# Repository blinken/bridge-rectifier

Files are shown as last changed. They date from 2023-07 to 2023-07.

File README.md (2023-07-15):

# Bench bridge rectifier

A really simple project - a bridge rectifier, with a fuse, designed to be
inserted into an aluminium case with banana plugs in and out. I wanted this to
safely dump 2A @ 250V AC into my DC electronic load (don't ask!)

The board is designed with 5mm separation between different nets.

The PCB is designed to slide in to rails in the aluminium extrusion, and the
edges of the PCB are left exposed so earth is electrically connected to the
enclosure.

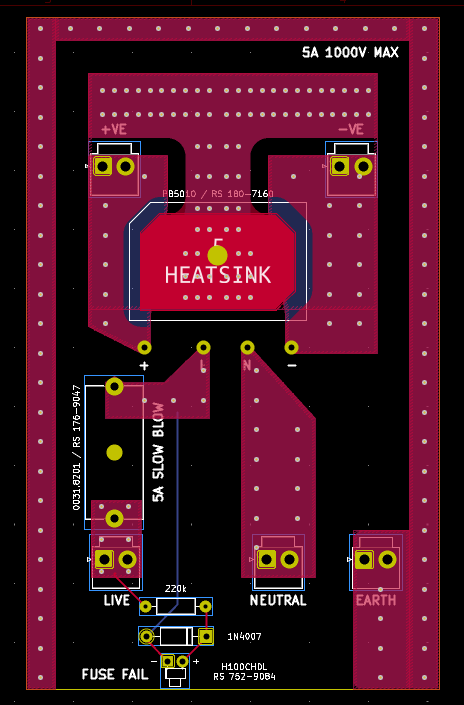
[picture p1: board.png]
Bridge rectifier PCB


## Bill of materials

 * Vishay PB5010 Bridge Rectifier, 45A, 1000V, 4-Pin (RS 180-7160)
 * 5x JST, VH, B2P, 2 Way, 1 Row, Straight PCB Header
 * Schurter 10A PCB Mount Fuse Holder 0031.8201 (RS 176-9047)
 * H100CHDL LED (RS 752-9084)
 * 1N4007 diode
 * 220k resistor, 0.25W or 0.5W
 * An aluminium extrusion case suitable for a 70x114mm board - eg, [AliExpress](https://www.aliexpress.com/item/1005003326971939.html)

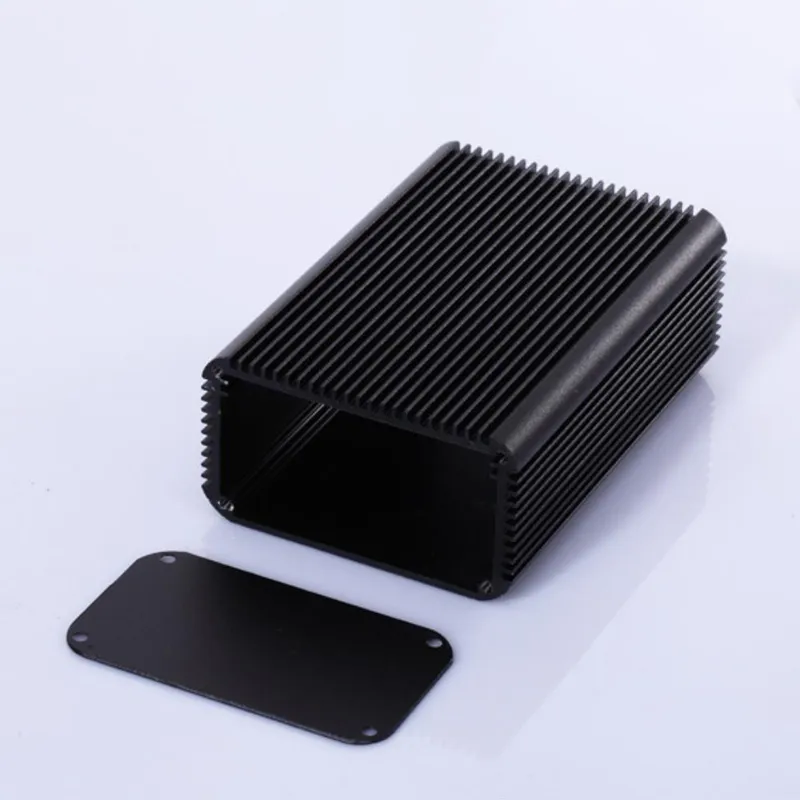
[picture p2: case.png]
Aluminium enclosure 70x115mm internal size

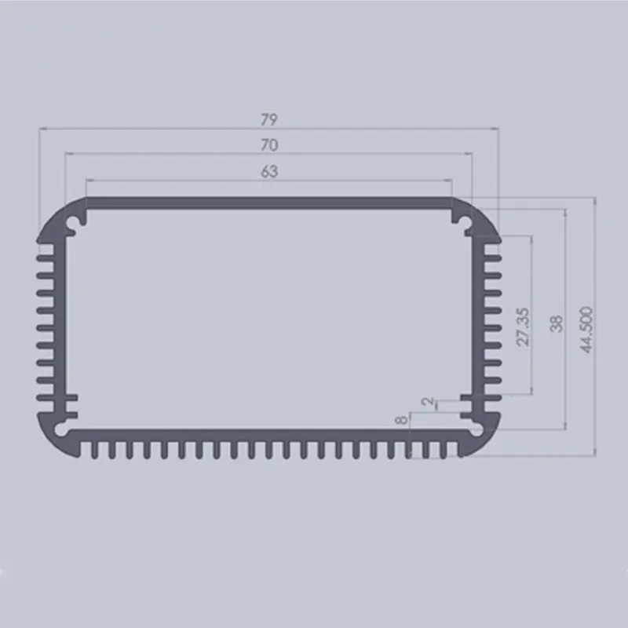
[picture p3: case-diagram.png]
Aluminium enclosure, diagram with dimensions


## License

[CC BY-SA 3.0](https://creativecommons.org/licenses/by-sa/3.0/)

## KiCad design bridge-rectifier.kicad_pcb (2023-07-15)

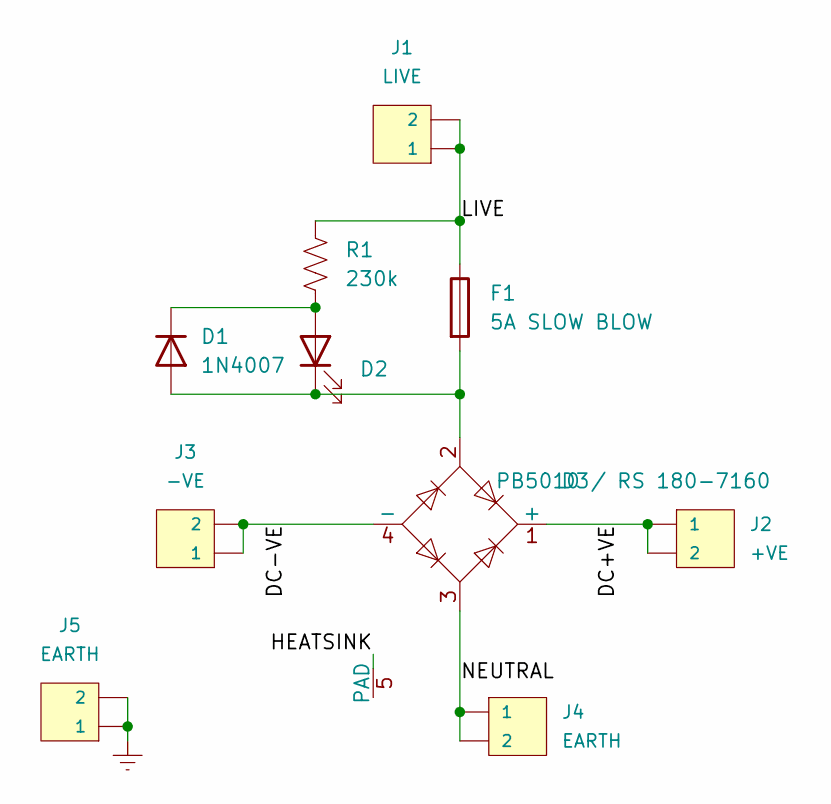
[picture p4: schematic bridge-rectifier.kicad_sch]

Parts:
D1: 1N4007; D_DO-41_SOD81_P10.16mm_Horizontal
D2: H100CHDLRS 752-9084; LED_D1.8mm_W1.8mm_H2.4mm_Horizontal_O1.27mm_Z1.6mm
D3: PB5010 / RS 180-7160; Vishay_Diode_Bridge_Rectifier_PB
F1: 5A SLOW BLOW; Fuseholder_Cylinder-5x20mm_Schurter_0031_8201_Horizontal_Op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
J1: LIVE; JST_VH_B2P-VH_1x02_P3.96mm_Vertical; LCSC C131337
J2: +VE; JST_VH_B2P-VH_1x02_P3.96mm_Vertical; LCSC C131337
J3: -VE; JST_VH_B2P-VH_1x02_P3.96mm_Vertical; LCSC C131337
J4, J5: EARTH; JST_VH_B2P-VH_1x02_P3.96mm_Vertical; LCSC C131337
R1: 230k; R_Axial_DIN0207_L6.3mm_D2.5mm_P10.16mm_Horizontal

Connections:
/DC+VE: D3.1 (+), J2.1, J2.2
/DC-VE: D3.4 (-), J3.1, J3.2
/HEATSINK: D3.5 (PAD)
/LIVE: F1.1, J1.1, J1.2, R1.1
/NEUTRAL: D3.3, J4.1, J4.2
Earth: J5.1, J5.2
unnamed: D1.1 (K), D2.2 (A), R1.2
unnamed: D1.2 (A), D2.1 (K), D3.2, F1.2

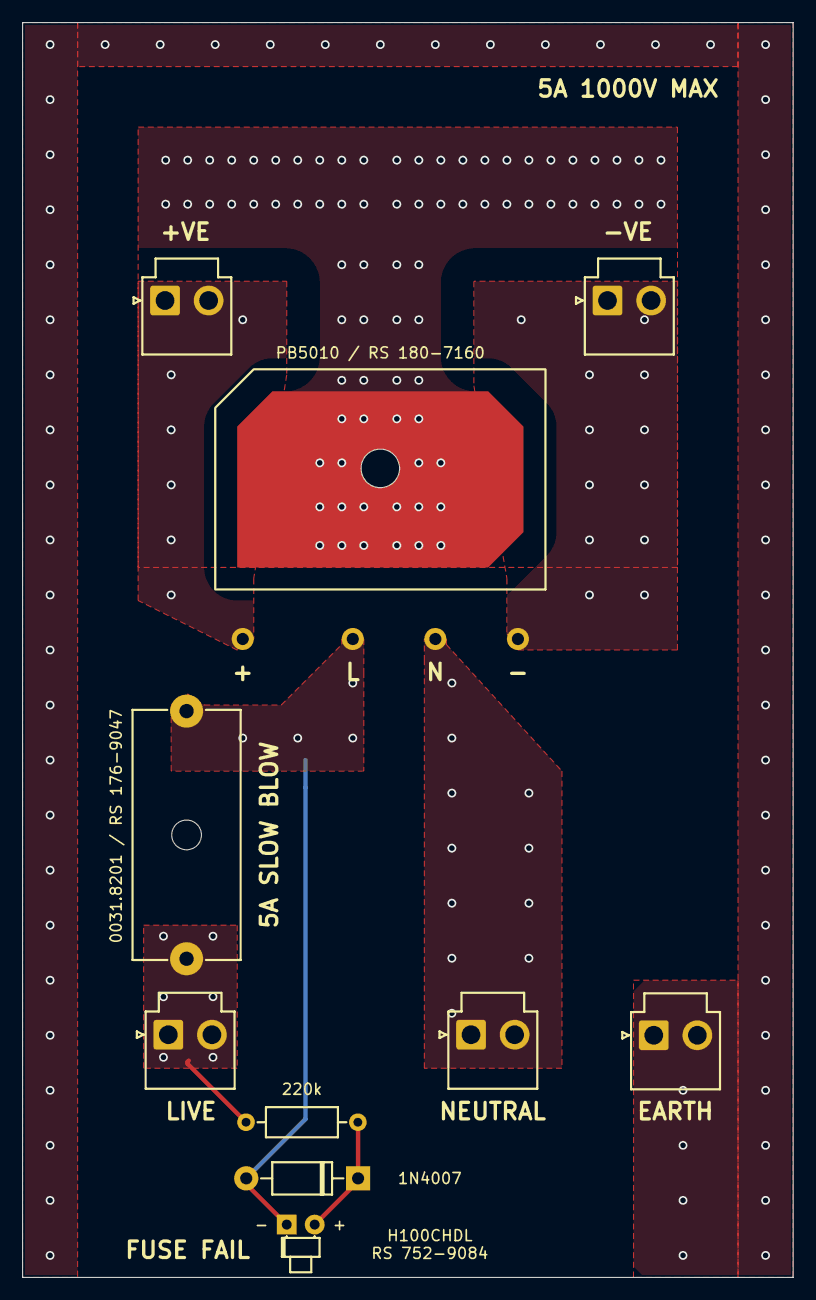
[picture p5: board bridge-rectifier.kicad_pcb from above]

Board: 2 copper layers, 70.0 x 114.0 mm, 10 parts (0 on the bottom side), 7 nets.

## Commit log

2023-07-14 bridge rectifier v1.0
    [bridge-rectifier-B_Cu.gbl, bridge-rectifier-B_Mask.gbs, bridge-rectifier-B_Paste.gbp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]
2023-07-15 Add README, LICENSE, case images
2023-07-15 Add PCB render
2023-07-15 Change resistor to a standard value & remove unnecessary dimension
    [bridge-rectifier.kicad_pcb]
